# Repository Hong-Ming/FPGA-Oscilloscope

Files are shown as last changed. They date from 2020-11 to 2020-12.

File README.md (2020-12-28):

# FPGA Oscilloscope

## Table of Contents
- [Intorduction](#intorduction)
- [Directory Tree](#directory-tree)
- [Project Info](#project-info)
- [Framework and Layout](#framework-and-layout)
- [Contributor](#contributor)

## Intorduction
We built a simple oscilloscope using Nexys 4 DDR board and PCB. First, the PCB transforms the input voltage signal into a signal with an acceptable voltage range for the FPGA board input, as well as generating knobs' control signal. The FPGA board then takes the processed signal and control signal to display waveforms, change voltage scale, adjust sweep time, etc. This work is the final project of the Digital Laboratory class at NCTU. [ [Demo Video](https://www.youtube.com/watch?v=sgIzcKYEROs&feature=youtu.be&ab_channel=AlexLi) ]

## Directory Tree
<pre>
FPGA_Oscilloscope/
├─ Demo Video/ ..................... 
│  └─ Demo Video.mp4 ............... 
├─ FPGA_Code/ ...................... System Verilog code for oscilloscope
│  ├─ Oscilloscope.sv .............. Main Function
│  ├─ Control.sv ................... Function for processing control signal
│  ├─ Sampling.sv .................. Function for sampling signal
│  ├─ Data_transfer.sv ............. Choose sample data based on scale
│  ├─ Sampling_time.sv ............. Choose sample time based on scale
│  ├─ VGA.sv ....................... Function for displaying information on screen.
│  ├─ Trig_display.sv .............. Display trigger info
│  ├─ Time_display.sv .............. Display time info
│  ├─ Channel_display.sv ........... Display waveform
│  ├─ Info_display.sv .............. Subfunction for displaying info
│  ├─ Trig_info.sv ................. Subfunction for displaying info
│  ├─ Time_info.sv ................. Subfunction for displaying info
│  ├─ Scale_tag.sv ................. For output scale
│  ├─ Word.sv ...................... For bitmap-fonts
│  ├─ Word_move.sv ................. For bitmap-fonts
│  ├─ DFF.sv ....................... D Flip flop
│  ├─ clk_div_2.sv ................. Clock
│  ├─ Clk_div_4.sv ................. Clock
│  ├─ clk_div_16.sv ................ Clock
│  └─ clk_div_256.sv ............... Clock
└─ PCB/ ............................ Input rectifier circuit design
   ├─ MAX6818.lbr .................. ICL7660CAS Library File
   ├─ Oscilloscope.brd ............. PCB board file
   ├─ Oscilloscope.sch ............. PCB schematic file
   └─ Gerber/ ...................... Directory contains layout files
</pre>

## Project Info
- **HDL**: [SystemVerilog](https://en.wikipedia.org/wiki/SystemVerilog)
- **FPGA Board**: [Nexys 4 DDR](https://reference.digilentinc.com/reference/programmable-logic/nexys-4-ddr/start)
- **PCB Layout Software**: [EAGLE](https://www.autodesk.com/products/eagle/overview?plc=F360&term=1-YEAR&support=ADVANCED&quantity=1)

## Framework and Layout
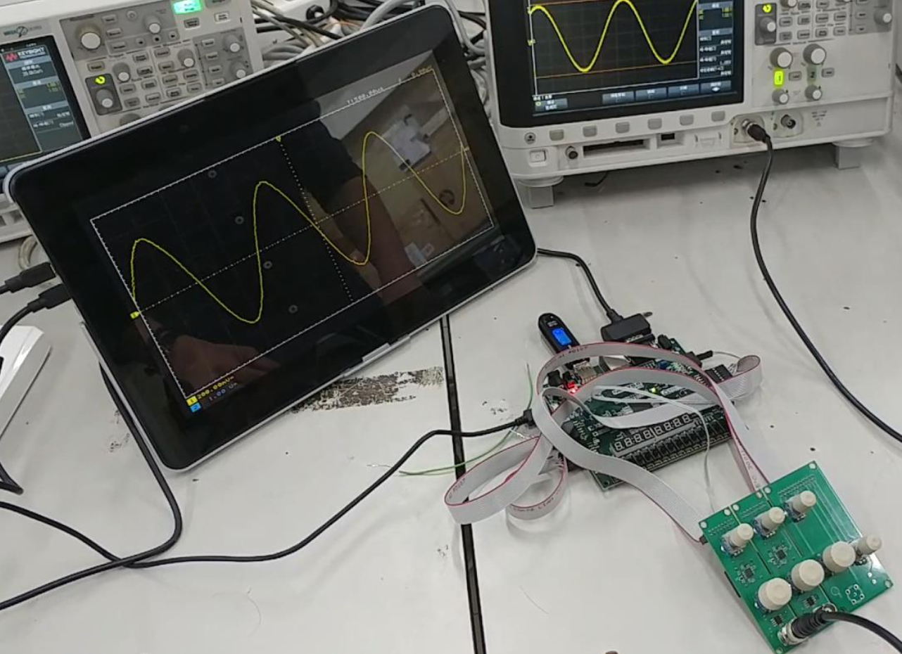
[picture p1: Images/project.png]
project picture

**Framework**:
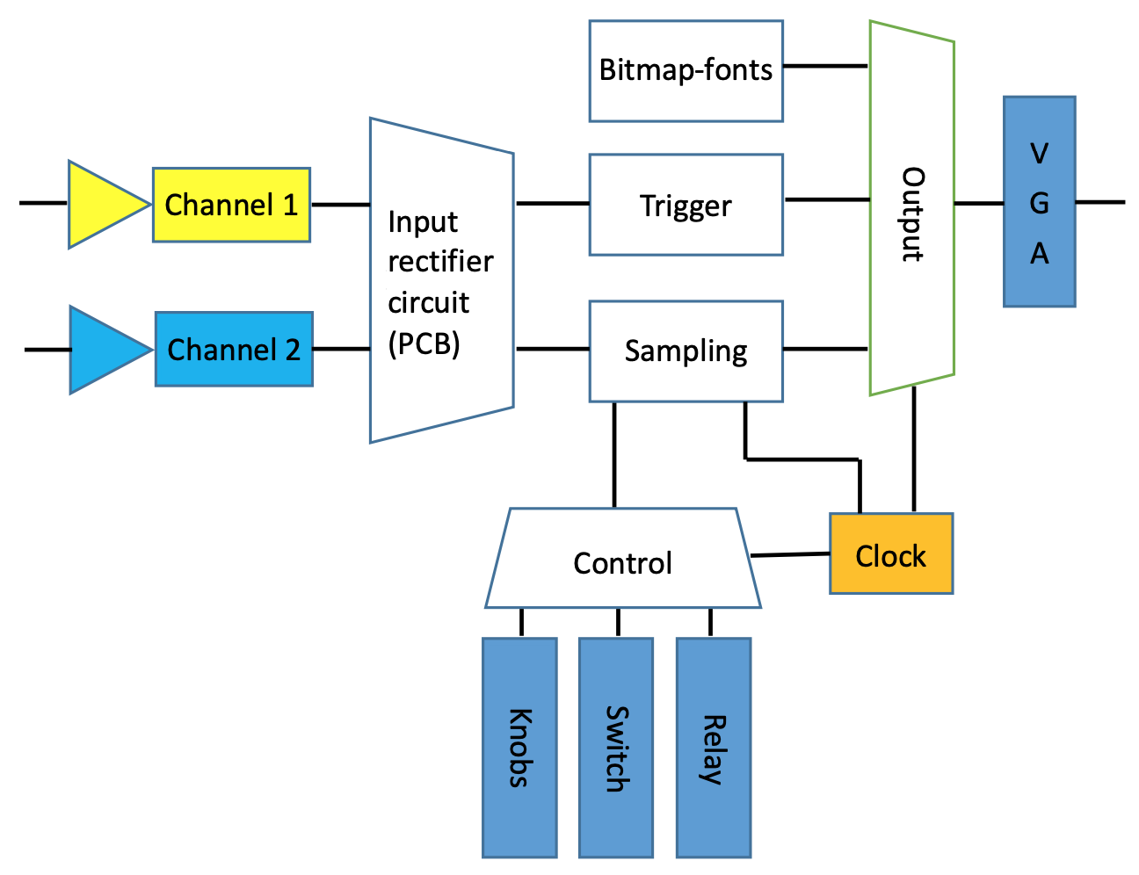
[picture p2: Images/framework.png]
framework

**Input Rectifier Circuit Schematic**:
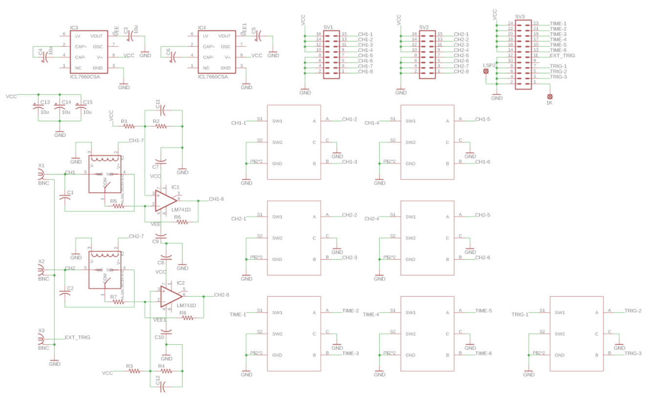
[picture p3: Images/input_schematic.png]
input circuit schematic

**Input Rectifier Circuit Layout**:
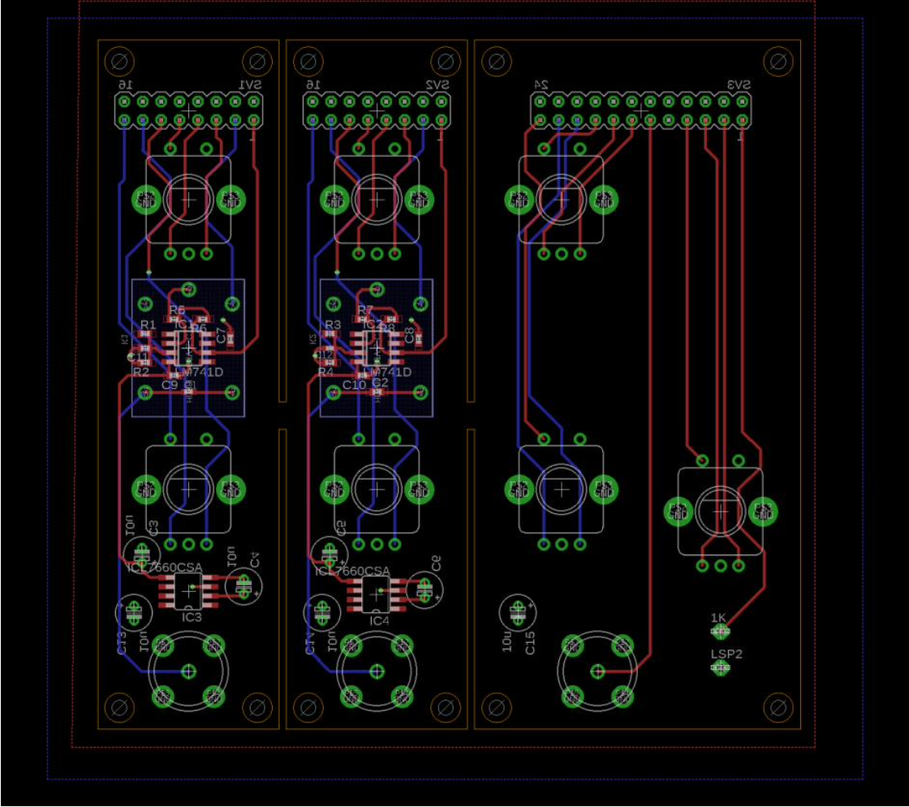
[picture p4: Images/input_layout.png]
input circuit layout


## Contributor
- [Hong-Ming Chiu](https://hong-ming.github.io/)
- [Huan-Jung Lee]()

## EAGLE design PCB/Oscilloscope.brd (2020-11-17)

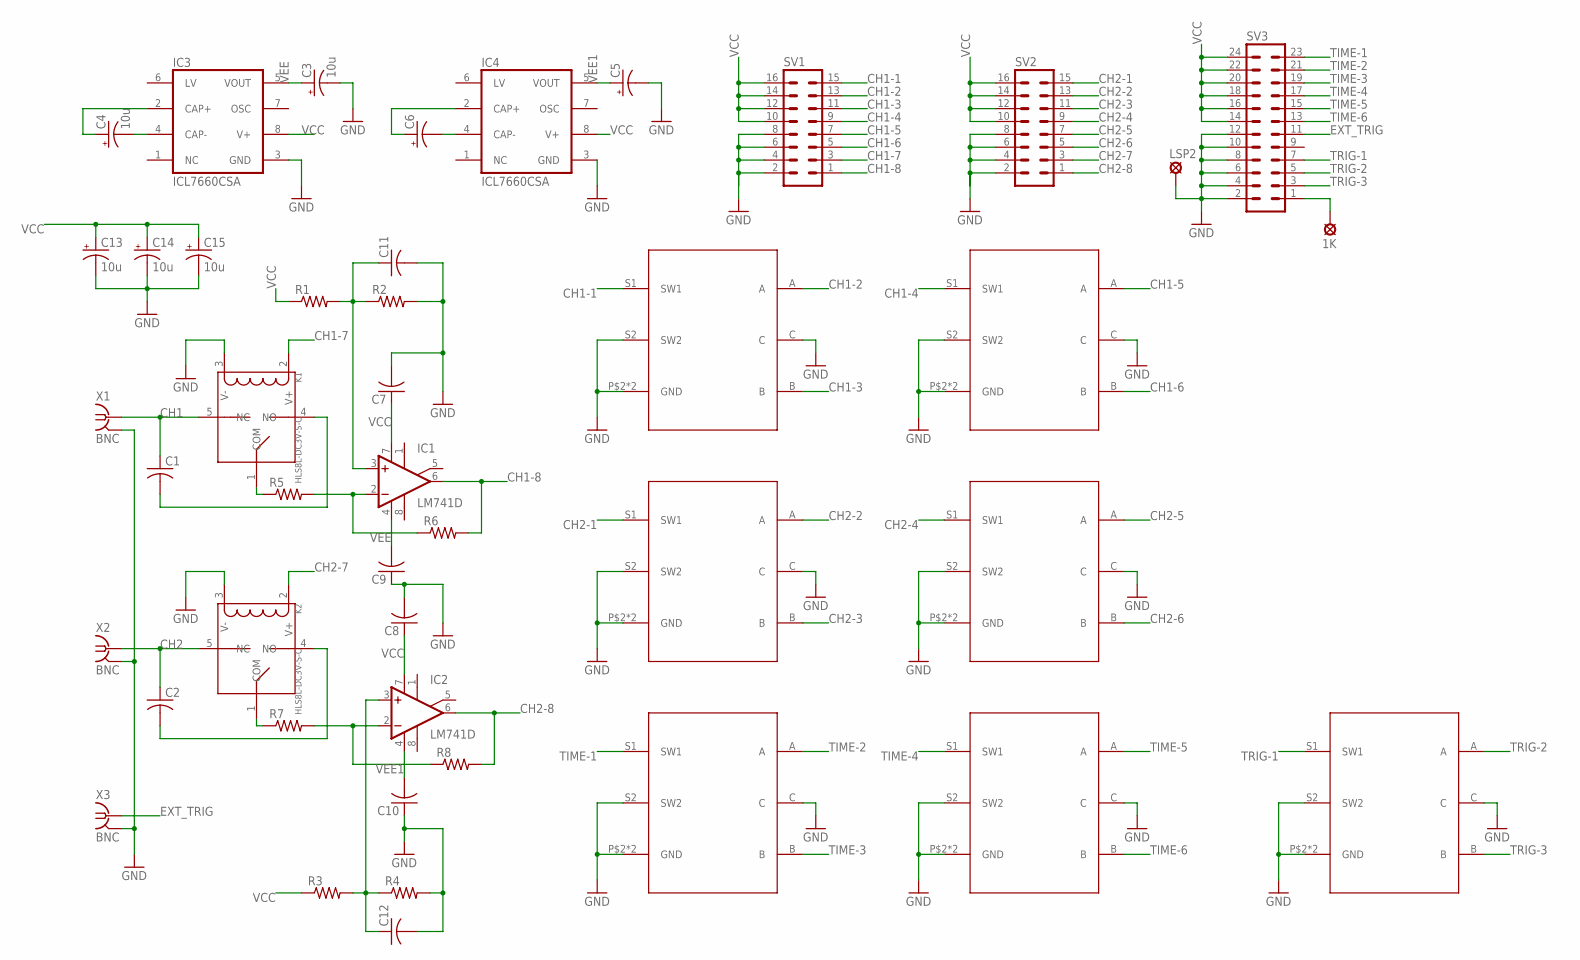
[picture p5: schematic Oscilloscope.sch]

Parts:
1K: LSP11
C1, C12: C-USC0402K; C0402K
C2, C7, C8, C9, C10, C11: C-USC0402; C0402
C3, C4, C13, C14, C15: 10u; E2-5
C5, C6: CPOL-USE2-5; E2-5
IC1, IC2: LM741D; SO08
IC3, IC4: ICL7660CSA; SO08
K1, K2: HLS8L-DC3V-S-C; REY5-19.0X15.0X15.0MM
LSP2: LSP11
R1, R2, R3, R4, R5, R6, R7, R8: R-US_R0402; R0402
SV1, SV2: MA08-2
SV3: MA12-2
U$2, U$3, U$4, U$5, U$6, U$7, U$8: EC11S
X1, X2, X3: BNC

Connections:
CH1: C1.1, K1.5 (NC), X1.P$1 (SIG)
CH1-1: SV1.15, U$3.S1 (SW1)
CH1-2: SV1.13, U$3.A
CH1-3: SV1.11, U$3.B
CH1-4: SV1.9, U$4.S1 (SW1)
CH1-5: SV1.7, U$4.A
CH1-6: SV1.5, U$4.B
CH1-7: K1.2 (V+), SV1.3
CH1-8: IC1.6 (OUT), R6.2, SV1.1
CH2: C2.1, K2.5 (NC), X2.P$1 (SIG)
CH2-1: SV2.15, U$2.S1 (SW1)
CH2-2: SV2.13, U$2.A
CH2-3: SV2.11, U$2.B
CH2-4: SV2.9, U$5.S1 (SW1)
CH2-5: SV2.7, U$5.A
CH2-6: SV2.5, U$5.B
CH2-7: K2.2 (V+), SV2.3
CH2-8: IC2.6 (OUT), R8.2, SV2.1
EXT_TRIG: SV3.11, X3.P$1 (SIG)
GND: C3.-, C5.-, C7.2, C8.2, C9.1, C10.1, C11.2, C12.2, C13.-, C14.-, C15.-, IC3.3 (GND), IC4.3 (GND), K1.3 (V-), K2.3 (V-), LSP2.MP, R2.2, R4.2, SV1.2, SV1.4, SV1.6, SV1.8, SV2.2, SV2.4, SV2.6, SV2.8, SV3.2, SV3.4, SV3.6, SV3.8, SV3.10, SV3.12, U$2.C, U$2.P$2 (GND), U$2.P$3 (GND), U$2.S2 (SW2), U$3.C, U$3.P$2 (GND), U$3.P$3 (GND), U$3.S2 (SW2), U$4.C, U$4.P$2 (GND), U$4.P$3 (GND), U$4.S2 (SW2), U$5.C, U$5.P$2 (GND), U$5.P$3 (GND), U$5.S2 (SW2), U$6.C, U$6.P$2 (GND), U$6.P$3 (GND), U$6.S2 (SW2), U$7.C, U$7.P$2 (GND), U$7.P$3 (GND), U$7.S2 (SW2), U$8.C, U$8.P$2 (GND), U$8.P$3 (GND), U$8.S2 (SW2), X1.P$2 (GND), X1.P$3 (GND), X1.P$4 (GND), X1.P$5 (GND), X2.P$2 (GND), X2.P$3 (GND), X2.P$4 (GND), X2.P$5 (GND), X3.P$2 (GND), X3.P$3 (GND), X3.P$4 (GND), X3.P$5 (GND)
unnamed: C1.2, K1.4 (NO)
unnamed: C2.2, K2.4 (NO)
unnamed: IC2.2 (-IN), R7.2, R8.1
unnamed: C4.-, IC3.4 (CAP-)
unnamed: C4.+, IC3.2 (CAP+)
unnamed: C6.-, IC4.4 (CAP-)
unnamed: C6.+, IC4.2 (CAP+)
unnamed: C11.1, IC1.3 (+IN), R1.2, R2.1
unnamed: C12.1, IC2.3 (+IN), R3.2, R4.1
unnamed: 1K.MP, SV3.1
unnamed: K1.1 (COM), R5.1
unnamed: IC1.2 (-IN), R5.2, R6.1
unnamed: K2.1 (COM), R7.1
TIME-1: SV3.23, U$6.S1 (SW1)
TIME-2: SV3.21, U$6.A
TIME-3: SV3.19, U$6.B
TIME-4: SV3.17, U$7.S1 (SW1)
TIME-5: SV3.15, U$7.A
TIME-6: SV3.13, U$7.B
TRIG-1: SV3.7, U$8.S1 (SW1)
TRIG-2: SV3.5, U$8.A
TRIG-3: SV3.3, U$8.B
VCC: C7.1, C8.1, C13.+, C14.+, C15.+, IC1.7 (V+), IC2.7 (V+), IC3.8 (V+), IC4.8 (V+), R1.1, R3.1, SV1.10, SV1.12, SV1.14, SV1.16, SV2.10, SV2.12, SV2.14, SV2.16, SV3.14, SV3.16, SV3.18, SV3.20, SV3.22, SV3.24
VEE: C3.+, C9.2, IC1.4 (V-), IC3.5 (VOUT)
VEE1: C5.+, C10.2, IC2.4 (V-), IC4.5 (VOUT)

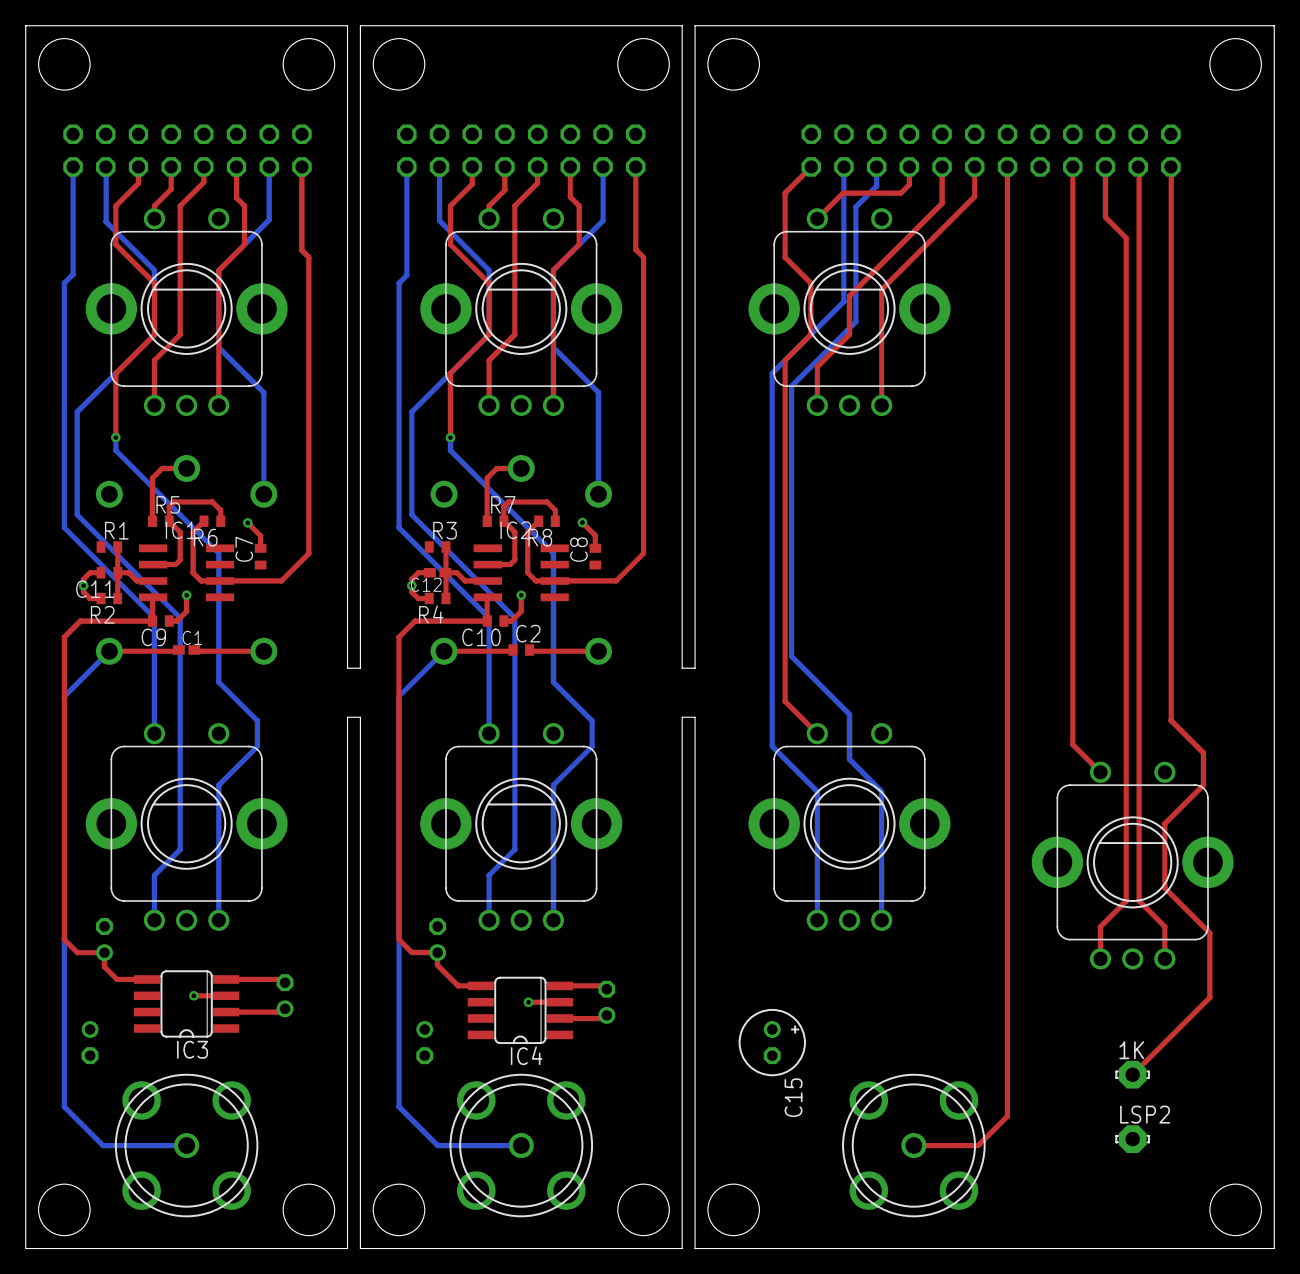
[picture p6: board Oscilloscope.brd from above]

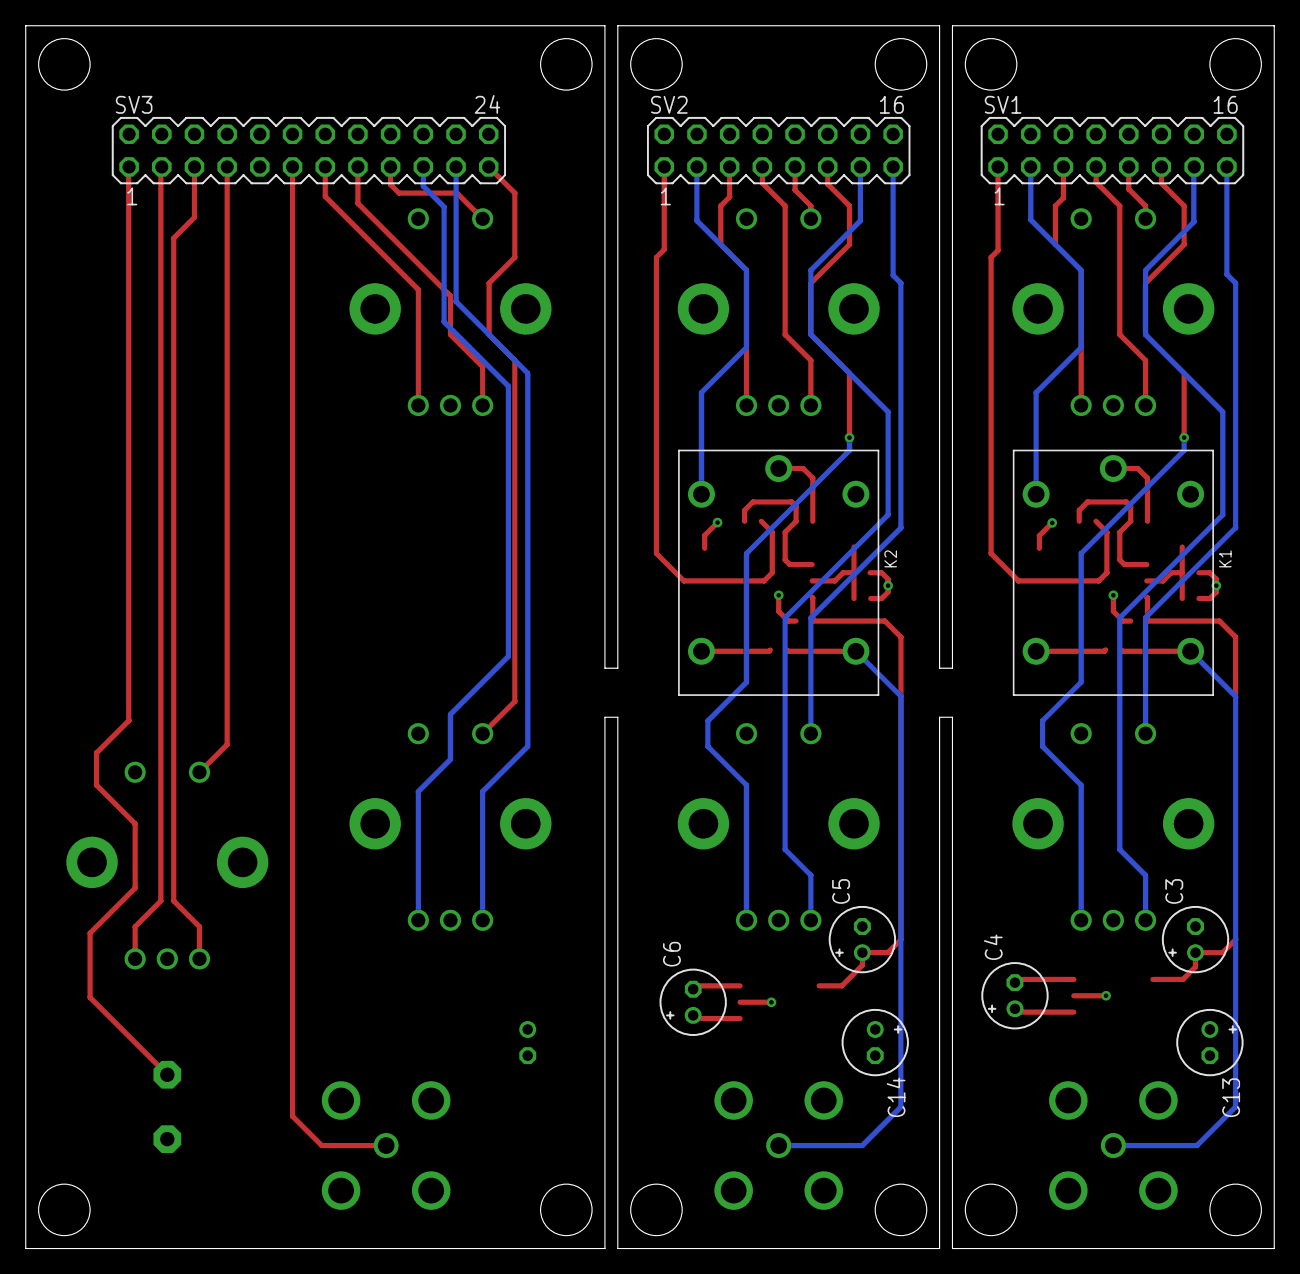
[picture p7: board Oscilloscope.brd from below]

Board: 2 copper layers, 97.0 x 95.0 mm, 44 parts (11 on the bottom side), 45 nets.

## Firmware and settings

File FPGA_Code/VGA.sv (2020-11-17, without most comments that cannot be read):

`timescale 1ns / 1ps

module VGA #(   parameter reg_size = 600,
                parameter h_pulse   = 96,    //H-SYNC pulse width 96 * 40 ns (25 Mhz) = 3.84 uS
                parameter h_bp      = 48,    //H-BP back porch pulse width
                parameter h_pixels  = 640,    //H-PIX Number of pixels horisontally
                parameter h_fp      = 16,    //H-FP front porch pulse width
                parameter h_pol     = 1'b0,    //H-SYNC polarity
                parameter h_frame   = 800,    //800 = 96 (H-SYNC) + 48 (H-BP) + 640 (H-PIX) + 16 (H-FP)
                parameter v_pulse   = 2,    //V-SYNC pulse width
                parameter v_bp      = 33,    //V-BP back porch pulse width
                parameter v_pixels  = 480,    //V-PIX Number of pixels vertically
                parameter v_fp      = 10,    //V-FP front porch pulse width
                parameter v_pol     = 1'b1,    //V-SYNC polarity
                parameter v_frame   = 525    // 525 = 2 (V-SYNC) + 33 (V-BP) + 480 (V-PIX) + 10 (V-FP)
                                            ) 
    (
        input CLK100MHz,
        input rst_n,
        input ch1_en,
        input ch2_en,
        input ch1_couple,
        input ch2_couple,
        input [9:0] ch1_offset,
        input [9:0] ch2_offset,
        input [9:0] trig,
        input [9:0] time_offset,
        input [3:0] ch1_scale,
        input [3:0] ch2_scale,
        input [4:0] time_scale,
        input [9:0] data_out_1 [reg_size - 1:0],
        input [9:0] data_out_2 [reg_size - 1:0],
        output logic [3:0] vga_r,
        output logic [3:0] vga_g,
        output logic [3:0] vga_b,
        output logic vga_hs,
        output logic vga_vs
        );
    
    logic       vga_clk, vga_hs_r, vga_vs_r, disp_en, reset = 1;    //H-SYNC register, V-SYNC register, display enable flag
    logic [1:0] clk_div;    // 2 bit counter
    logic [3:0] vga_r_r, vga_g_r, vga_b_r;    //VGA color registers R,G,B x 3 bit
    logic [7:0] timer_t = 0;    // 8 bit timer with 0 initialization
    logic [8:0] ch1, ch2, trigger, time_zero;
    logic [9:0] c_row, c_col, c_hor, c_ver;        //complete frame register row, complete frame register colum, visible frame register horisontally, visible  frame register vertically
        
    logic [4:0] ch1_mode, ch2_mode;
    assign ch1_mode = (ch1_couple)? 5'd15 : 5'd14;
    assign ch2_mode = (ch2_couple)? 5'd15 : 5'd14;
        
    logic trig_info_dis, time_info_dis, ch1_info_light, ch1_info_dark, ch2_info_light, ch2_info_dark;
    logic [11:0] color, ch1_color, ch2_color, trig_color, white, gray, black;
    
    assign {vga_r_r, vga_g_r, vga_b_r} = color;
    assign ch1_color = {4'd15, 4'd15, 4'd0};
    assign ch2_color = {4'd3, 4'd11, 4'd15};
    assign trig_color = {4'd15, 4'd11, 4'd0};
    assign white = {4'd15, 4'd15, 4'd15};
    assign gray = {4'd7, 4'd7, 4'd7};
    assign black = {4'd0, 4'd0, 4'd0};
    
    assign     vga_r         = vga_r_r;        //assign the output signals for VGA to the VGA registers
    assign     vga_g         = vga_g_r;
    assign     vga_b         = vga_b_r;
    assign     vga_hs         = vga_hs_r;
    assign     vga_vs         = vga_vs_r;

    Clk_div_4 clk_div_4(.clk_in(CLK100MHz), .clk_out(vga_clk), .rst_n(rst_n));
    
    always_comb begin
        ch1         = 440 - ch1_offset;
        ch2         = 440 - ch2_offset;
        trigger     = 440 - trig;
        time_zero   = 20 + time_offset;
    end
    
    always @ (posedge vga_clk) begin                //25Mhz clock
    
        if(timer_t > 250) reset <= 0;                // generate 10 uS RESET signal 
        else begin
            reset <= 1;                    //while in reset display is disabled, suare is set to initial position
            timer_t <= timer_t + 1;
            disp_en <= 0;            
        end
        
        if(reset == 1) begin                    //while RESET is high init counters
            c_hor <= 0;
            c_ver <= 0;
            vga_hs_r <= 1;
            vga_vs_r <= 0;
            c_row <= 0;
            c_col <= 0;
        end else begin                        // update current beam position
            if(c_hor < h_frame - 1) c_hor <= c_hor + 1;
            else begin
                c_hor <= 0;
                if(c_ver < v_frame - 1) c_ver <= c_ver + 1;
                else c_ver <= 0;
            end
        end
        if((c_hor < (h_pixels + h_fp + 1)) | (c_hor > (h_pixels + h_fp + h_pulse))) vga_hs_r <= ~h_pol;    // H-SYNC generator
        else vga_hs_r <= h_pol;
        if((c_ver < (v_pixels + v_fp)) | (c_ver > (v_pixels + v_fp + v_pulse))) vga_vs_r <= ~v_pol;        //V-SYNC generator
        else vga_vs_r <= v_pol;
        if(c_hor < h_pixels) c_col <= c_hor;        //c_col and c_row counters are updated only in the visible time-frame
        if(c_ver < v_pixels) c_row <= c_ver;
        if(c_hor < h_pixels && c_ver < v_pixels) disp_en <= 1;        //VGA color signals are enabled only in the visible time frame
        else disp_en <= 0;
        
        if(disp_en == 1 & reset == 0) begin
            color <= black;
            if(c_row >= 40 & c_col >= 20 & c_row <= 440 & c_col <= 620) begin
                if(c_row == 40 | c_col == 20 | c_row == 440 | c_col == 620) begin
                    color <= white;
                end else begin
                    if(((c_row == 240) & ((c_col-20)%10 == 0)) | ((c_col == 320) & ((c_row-40)%10 == 0)));
                    else if(((c_row-40)%50==0 & c_col%5 == 0) | ((c_col-20)%50==0 & c_row%5 == 0)) color <= gray;
                    
                    if(((c_row == 41 | c_row == 42 | c_row == 239 | c_row == 240 | c_row == 241 | c_row == 438 | c_row == 439) & (c_col-20)%10 == 0) |
                       ((c_col == 21 | c_col == 22 | c_col == 319 | c_col == 320 | c_col == 321 | c_col == 618 | c_col == 619) & (c_row-40)%10 == 0) ) color <= white;
                    
                    if(c_row == trigger & c_col%3 == 0) color <= trig_color;    //trigger level
                    
                    if( ch2_en & ((c_row >= data_out_2[c_col-21] & c_row <= data_out_2[c_col-20]) | (c_row <= data_out_2[c_col-21] & c_row >= data_out_2[c_col-20])) ) color <= ch2_color;
                    
                    if( ch1_en & ((c_row >= data_out_1[c_col-21] & c_row <= data_out_1[c_col-20]) | (c_row <= data_out_1[c_col-21] & c_row >= data_out_1[c_col-20])) ) color <= ch1_color;
                    
                end
                
               /*********************************************************time_tag*********************************************************/
                if((c_row > 40) & (c_col <= time_zero + 3) & (c_col >= time_zero - 3) &
                   ( ((time_zero < c_col) & (c_row < 50 - c_col + time_zero)) |
                     ((time_zero > c_col) & (c_row < 50 + c_col - time_zero)) |
                     ((c_col == time_zero) & (c_row == 41 | ((c_row > 46) & (c_row < 50)))) ) ) color <= trig_color;
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

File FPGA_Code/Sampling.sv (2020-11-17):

`timescale 1ns / 1ps

module Sampling #(parameter reg_size = 600) (
    input rst_n,
    input CLK100MHz,
    input vauxp2,
    input vauxn2,
    input vauxp3,
    input vauxn3,
    input trig_off,
    input ch1_en,
    input ch2_en,
    input ch1_couple,
    input ch2_couple,
    input [3:0] ch1_scale,
    input [3:0] ch2_scale,
    input [4:0] time_scale,
    input [9:0] trig,
    input [9:0] ch1_offset,
    input [9:0] ch2_offset,
    output logic [9:0] data_out_1 [reg_size - 1:0],
    output logic [9:0] data_out_2 [reg_size - 1:0],
    output logic clk_sampling
    );
    
    logic enable1, enable2, out_clk,  GND, out_en, dis_en, ready1, ready2;//, clk_sampling;
    logic [1:0] reg_count;
    logic [7:0] Address_in_ch1, Address_in_ch2, clk_count, daddr_in;
    logic [9:0] trig_level;
    logic [9:0] data_reg [3:0];
    logic [15:0] data_count, do_out, data_ch1, data_ch2, out_count, sample_count;
    logic [31:0] data_cal_ch1, data_cal_ch2, data_tran, dis_count, time_sampling;
    
    assign trig_level = 440 - trig;
    assign Address_in_ch1 = 8'h12;
    assign Address_in_ch2 = 8'h13;
    
   //xadc instantiation connect the eoc_out .den_in to get continuous conversion
    xadcwiz  xadc_ch1 ( .daddr_in, //addresses can be found in the artix 7 XADC user guide DRP register space
                        .dclk_in(CLK100MHz), 
                        .den_in(enable1),                   
                        .vauxp2, .vauxn2, .vauxp3, .vauxn3,
                        .do_out, 
                        .di_in(16'd0), .dwe_in(1'b0), .vp_in(1'b0), .vn_in(1'b0), .reset_in(1'b0),
                        .eoc_out(enable1),
                        .drdy_out(ready1));

    always @(posedge CLK100MHz, negedge rst_n) begin
        if(~rst_n) dis_count <= 0;
        else begin
            dis_count <= dis_count + 1;
            if(dis_count >= time_sampling) dis_count <= 0;
        end
    end
    
    assign clk_sampling = (dis_count <= time_sampling/2);
    
    always @(posedge clk_sampling, negedge rst_n) begin
        if(~rst_n) daddr_in <= Address_in_ch1; 
        else begin
            if(daddr_in == Address_in_ch1) begin
                daddr_in <= Address_in_ch2;
                data_ch1 <= do_out;
            end else begin
                daddr_in <= Address_in_ch1;
                data_ch2 <= do_out;
            end
        end
    end

    always @(posedge CLK100MHz, negedge rst_n) begin
        if(~rst_n) begin
            reg_count <= 0;
        end else begin
            if(dis_count == 0) begin
                data_reg[reg_count] <= data_cal_ch1;
                reg_count <= reg_count - 1;
            end
        end
    end
    
    always @(posedge CLK100MHz, negedge rst_n) begin
        if(~rst_n) begin
            dis_en <= 0;
        end else begin
            if(data_reg[0] <= trig_level & data_reg[1] <= trig_level & data_reg[2] >= trig_level & data_reg[3] >= trig_level &
                data_reg[0] <= data_reg[1] & data_reg[1] <= data_reg[2] & data_reg[2] <= data_reg[3]) dis_en <= 1;
            else if(~rst_n | data_count >= reg_size - 1)  dis_en <= 0;
        end
    end
        
    always @(posedge clk_sampling, negedge rst_n) begin
        if(~rst_n) data_count <= 0;
        else if(dis_en | trig_off) begin
            data_out_1[data_count] <= data_cal_ch1;
            data_out_2[data_count] <= data_cal_ch2;
            if(data_count >= reg_size - 1) data_count <= 0;
            else data_count <= data_count + 1;
        end
    end
    
    Data_transfer ch1_data_transfer(.couple_in(ch1_couple), .offset_in(ch1_offset), .scale_in(ch1_scale), .data_in(data_ch1), .data_out(data_cal_ch1));
    Data_transfer ch2_data_transfer(.couple_in(ch2_couple), .offset_in(ch2_offset), .scale_in(ch2_scale), .data_in(data_ch2), .data_out(data_cal_ch2));
    Sampling_time sampling_time(.scale_in(time_scale), .time_sampling);
    
endmodule
